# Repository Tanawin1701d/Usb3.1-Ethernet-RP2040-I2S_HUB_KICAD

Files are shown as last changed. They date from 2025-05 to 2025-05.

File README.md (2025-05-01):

# Usb3.1-Ethernet-RP2040-I2S_HUB_KICAD

- This project relies on Kicad 9.0

## features

### input
- usb 3.1 gen2
### output
- usb 3.0 (2 ports)
- ethernet (1 rj45 port)
- microphone + speaker (stero 3mm jack)
### processor & ic
- Rasberry pi (RP2040)
- tmp235 (temperature sensor)
- tusb8041 (usb hub)
- RTL8153B-VB (ethernet)

### repo structure

```
F---- doc (document for each ICs)
F---- finalProj
           |F---- hub (kicad file)
F---- symFoot (footprint for each ICs)
D---- bom.xlsx (bill of material for all components except pcb board)
```

## preview

### schematic

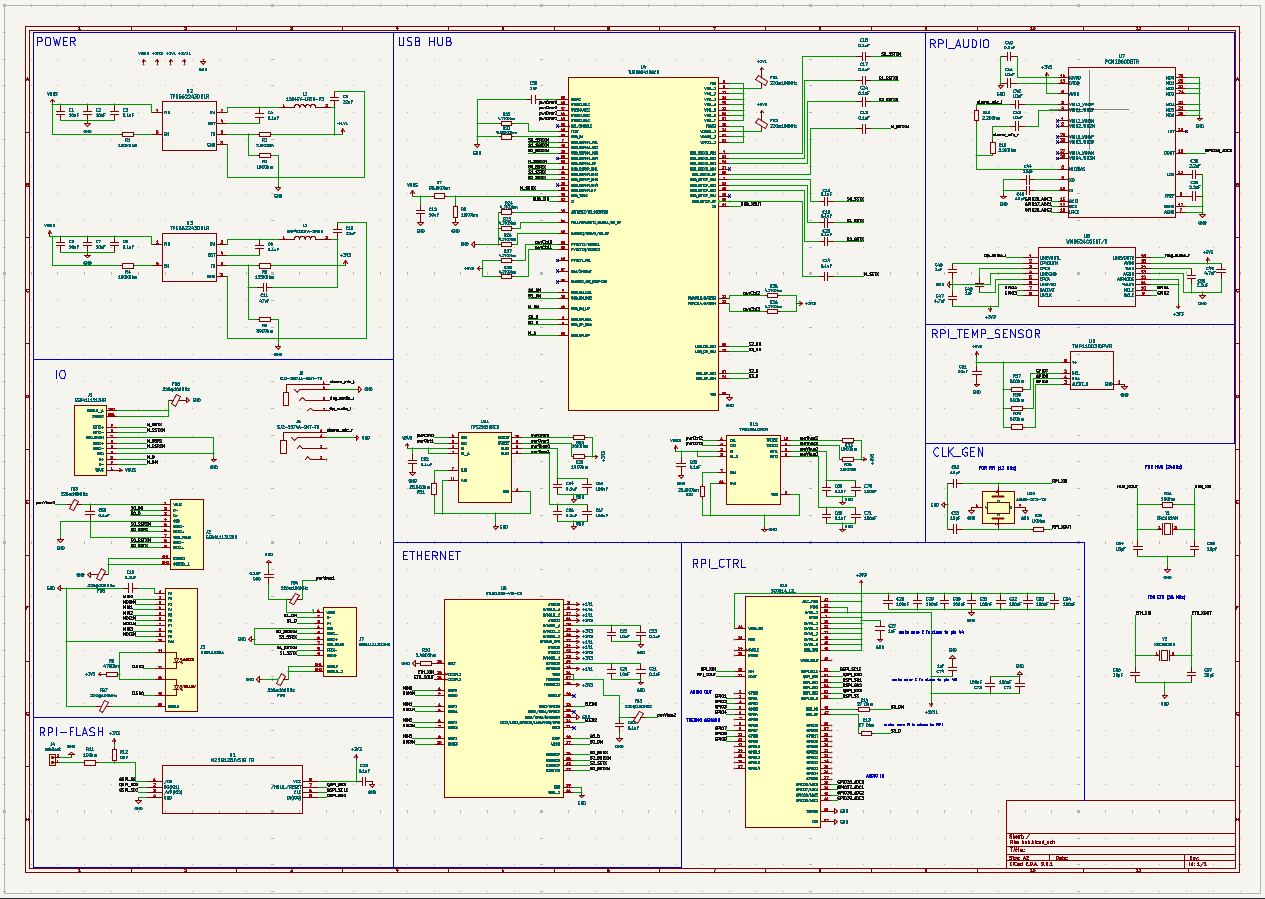
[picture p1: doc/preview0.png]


### layout

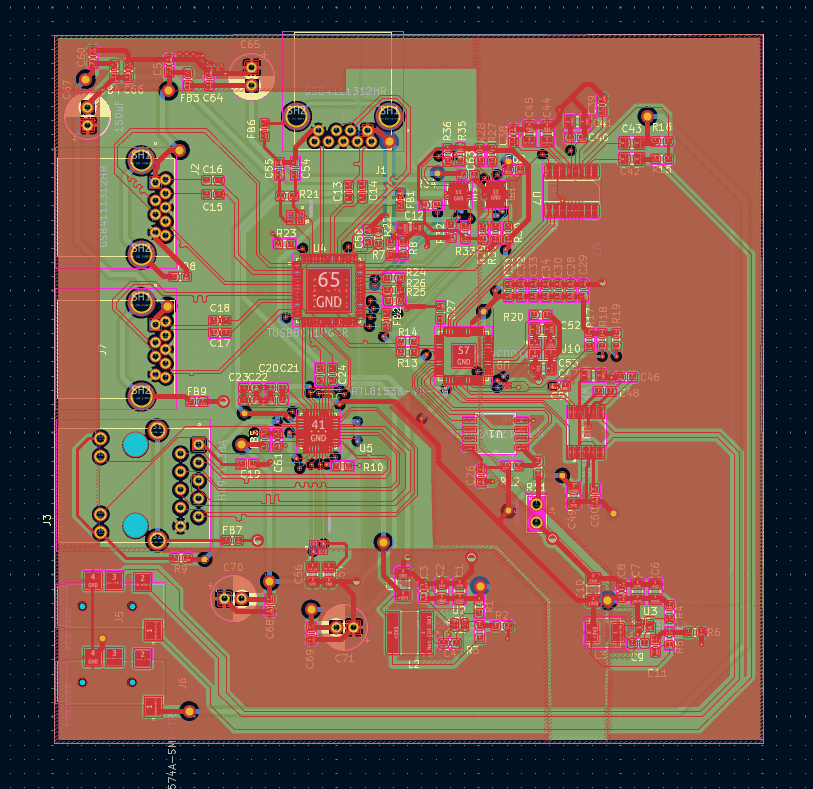
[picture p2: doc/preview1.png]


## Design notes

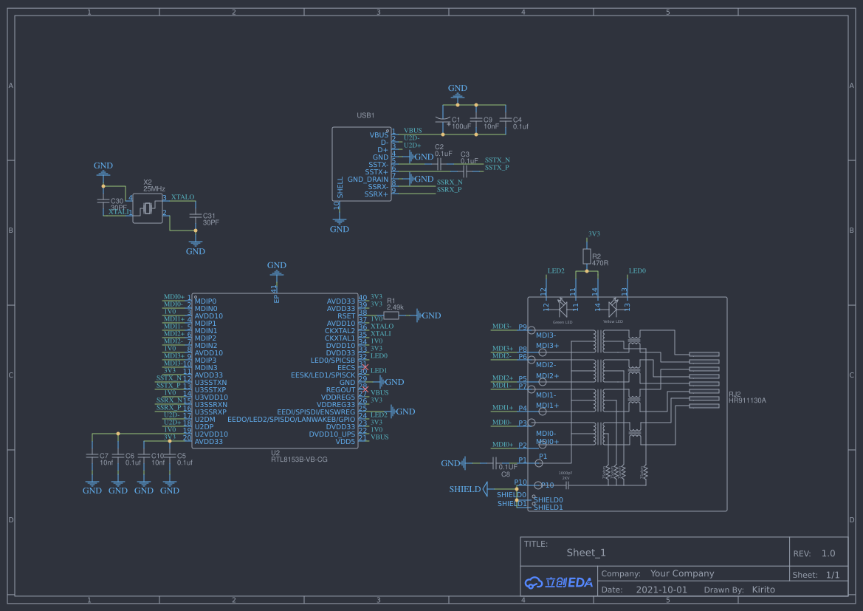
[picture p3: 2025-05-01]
symFoot/ethernetExample.png

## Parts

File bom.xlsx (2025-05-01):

Reference | Footprint | voltage rating | tol | temp coff | price |  |  |  | Value | Datasheet | DNP | Exclude from BOM | Exclude from Board | source
C1,C2,C6,C7,C12,C41,C42,C43 | Capacitor_SMD:C_0805_2012Metric_Pad1.18x1.45mm_HandSolder | 10 | +-10 | x7r | 0.38 |  | 8 | 3.04 | 10uF | ~ |  |  |  | https://www.digikey.co.th/en/products/detail/samsung-electro-mechanics/CL21B106KPQNNNE/3887422
C3,C4,C8,C9,C13,C14,C15,C16,C17,C18,C19,C21,C23,C24,C25,C26,C40,C59,C60,C61,C62,C63,C64,C66,C68,C69 | Capacitor_SMD:C_0603_1608Metric_Pad1.08x0.95mm_HandSolder | 25 | +-10 | x7r | 0.01500 |  | 26 | 0.39 | 0.1uF | ~ |  |  |  | https://www.digikey.co.th/en/products/detail/samsung-electro-mechanics/CL10B104KA8NNNC/3886664
C5,C10 | Capacitor_SMD:C_1206_3216Metric_Pad1.33x1.80mm_HandSolder | 10 | +-20 | x7r | 0.20300 |  | 2 | 0.406 | 22uF | ~ |  |  |  | https://www.digikey.co.th/en/products/detail/samsung-electro-mechanics/CL31B226MPHNNNE/3888806
C11 | Capacitor_SMD:C_0603_1608Metric_Pad1.08x0.95mm_HandSolder | 50 | +-10 | x7r | 0.10200 |  | 1 | 0.102 | 47pF | ~ |  |  |  | https://www.digikey.co.th/en/products/detail/kyocera-avx/06035C470KAT2A/3080637
C20,C22,C51 | Capacitor_SMD:C_0603_1608Metric_Pad1.08x0.95mm_HandSolder | 50 | +-10 | x7r | 0.00900 |  | 3 | 0.027 | 10nF | ~ |  |  |  | https://www.digikey.co.th/en/products/detail/samsung-electro-mechanics/CL10B103KB8NNNC/3886667
C27,C46,C48,C58,C74 | Capacitor_SMD:C_0603_1608Metric_Pad1.08x0.95mm_HandSolder | 10 | +-10 | x7r | 0.00600 |  | 5 | 0.03 | 1uF | ~ |  |  |  | https://www.digikey.co.th/en/products/detail/samsung-electro-mechanics/CL10B105KP8NNNC/3887604
C28,C29,C30,C31,C32,C33,C34,C72,C73 | Capacitor_SMD:C_0603_1608Metric_Pad1.08x0.95mm_HandSolder | 25 | +-10 | x7r | 0.01500 |  | 9 | 0.135 | 0.1uF | ~ |  |  |  | https://www.digikey.co.th/en/products/detail/samsung-electro-mechanics/CL10B104KA8NNNC/3886664
C38,C39,C50 | Capacitor_SMD:C_0603_1608Metric_Pad1.08x0.95mm_HandSolder | 10 | +-10 | x7r | 0.02100 |  | 3 | 0.063 | 2.2uF | ~ |  |  |  | https://www.digikey.co.th/en/products/detail/samsung-electro-mechanics/CL10B225KP8NNNC/3886792
C44,C45,C52,C53 | Capacitor_SMD:C_0805_2012Metric_Pad1.18x1.45mm_HandSolder | 50 | +-10 | x7r | 0.10600 |  | 4 | 0.424 | 15pF | ~ |  |  |  | https://www.digikey.co.th/en/products/detail/kyocera-avx/08055C150KAT2A/1602879
C47,C49 | Capacitor_SMD:C_0805_2012Metric_Pad1.18x1.45mm_HandSolder | 16 | +-10 | x7r | 0.10800 |  | 2 | 0.216 | 4.7uF | ~ |  |  |  | https://www.digikey.co.th/en/products/detail/samsung-electro-mechanics/CL21B475KOFNFNE/3888628
C54,C55 | Capacitor_SMD:C_0603_1608Metric_Pad1.08x0.95mm_HandSolder | 50 | +-10 | x7r | 0.12900 |  | 2 | 0.258 | 18pF | ~ |  |  |  | https://www.digikey.co.th/en/products/detail/kemet/C0603C180K5RACTU/12700994
C56,C57 | 0805 (2012 Metric) | 50 | +-10 | x7r | 0.17300 |  | 2 | 0.346 | 30pF | ~ |  |  |  | https://www.digikey.co.th/en/products/detail/kemet/C0805C300K5RACAUTO/18127792
C65,C67,C70,C71 | custom (polar ) | 6.3 | +-20 | x7r | 0.22400 |  | 4 | 0.896 | 150uF | ~ |  |  |  | https://www.digikey.co.th/en/products/detail/rubycon/25ZLJ150M6-3X11/3134203
FB1,FB2,FB3,FB4,FB5,FB6,FB7,FB8,FB9 | 603 |  |  |  | 0.057 |  | 9 | 0.513 | 220@100MHz | ~ |  |  |  | https://www.digikey.co.th/en/products/detail/tdk-corporation/MPZ1608S221ATA00/571872
J1 | GSB4111312HR:AMPHENOL_GSB4111312HR |  |  |  | 0.92 |  | 3 | 2.76 | GSB4111312HR |  |  |  |  | https://www.digikey.co.th/en/products/detail/amphenol-cs-commercial-products/GSB4111312HR/4883780
J3 | HR911130A:HANRUN_HR911130A |  |  |  | 1.14302 |  | 1 | 1.14302 | HR911130A |  |  |  |  | https://www.chipspulse.com/product/Hanrun/HR911130A.html?utm_source=digipart&sku=HR911130A
J4 | pin01x02:61300211121 |  |  |  | 0.113 |  | 1 | 0.113 | usbBoot |  |  |  |  | https://th.mouser.com/ProductDetail/Wurth-Elektronik/61300211121?qs=t4813l51qx%252B1A5GYDQxPlw%3D%3D
J5,J6 | SJ2_3574A_SMT_TR:SAMESKY_SJ2-3574A-SMT-TR |  |  |  | 0.87 |  | 2 | 1.74 | SJ2-3574A-SMT-TR |  |  |  |  | https://www.digikey.co.th/en/products/detail/same-sky-formerly-cui-devices/SJ2-3574A-SMT-TR/6619530
L1 | custom |  |  |  | 0.328 |  | 1 | 0.328 | 1.2uH | ~ |  |  |  | https://www.digikey.co.th/en/products/detail/murata-electronics/1264EY-1R2N-P3/6205581
L2 | custom |  |  |  | 0.838 |  | 1 | 0.838 | 3.3uH(SRP4020TA_3R3M) | ~ |  |  |  | https://www.digikey.co.th/en/products/detail/bourns-inc/SRP4020TA-3R3M/4901005
R1,R4 | Resistor_SMD:R_0603_1608Metric_Pad0.98x0.95mm_HandSolder |  |  |  | 0.027 |  | 2 | 0.054 | 100KOhm | ~ |  |  |  | https://www.digikey.co.th/en/products/detail/susumu/RR0816P-104-D/432233
R2,R8,R29,R30,R33,R34 | Resistor_SMD:R_0603_1608Metric_Pad0.98x0.95mm_HandSolder |  |  |  | 0.033 |  | 6 | 0.198 | 10KOhm | ~ |  |  |  | https://www.digikey.co.th/en/products/detail/panasonic-electronic-components/ERJ-3GEYJ103V/135662
R3 | Resistor_SMD:R_0603_1608Metric_Pad0.98x0.95mm_HandSolder |  |  |  | 0.009 |  | 1 | 0.009 | 7.5KOhm | ~ |  |  |  | https://www.digikey.co.th/en/products/detail/yageo/RC0603FR-077K5L/727366
R5 | Resistor_SMD:R_0603_1608Metric_Pad0.98x0.95mm_HandSolder |  |  |  | 0.101 |  | 1 | 0.101 | 135KOhm | ~ |  |  |  | https://www.digikey.co.th/en/products/detail/yageo/RT0603BRD07135KL/5927893
R6 | Resistor_SMD:R_0603_1608Metric_Pad0.98x0.95mm_HandSolder |  |  |  | 0.008 |  | 1 | 0.008 | 30KOhm | ~ |  |  |  | https://www.digikey.co.th/en/products/detail/yageo/RC0603JR-0730KL/726768
R7 | Resistor_SMD:R_0603_1608Metric_Pad0.98x0.95mm_HandSolder |  |  |  | 0.009 |  | 1 | 0.009 | 90.9KOhm | ~ |  |  |  | https://www.digikey.co.th/en/products/detail/yageo/RC0603FR-0790K9L/727424
R9 | Resistor_SMD:R_0603_1608Metric_Pad0.98x0.95mm_HandSolder |  |  |  | 0.008 |  | 1 | 0.008 | 470Ohm | ~ |  |  |  | https://www.digikey.co.th/en/products/detail/yageo/RC0603JR-07470RL/726791
R10 | Resistor_SMD:R_0603_1608Metric_Pad0.98x0.95mm_HandSolder |  |  |  | 0.03 |  | 1 | 0.03 | 2.49KOhm | ~ |  |  |  | https://www.digikey.co.th/en/products/detail/vishay-dale/CRCW06032K49FKEAC/7928466
R11,R20 | Resistor_SMD:R_0603_1608Metric_Pad0.98x0.95mm_HandSolder |  |  |  | 0.02 |  | 2 | 0.04 | 1KOhm | ~ |  |  |  | https://www.digikey.co.th/en/products/detail/stackpole-electronics-inc/RMCF0603FT1K00/1761077
R12 | Resistor_SMD:R_0603_1608Metric_Pad0.98x0.95mm_HandSolder |  |  |  |  |  |  | 0 | DNF | ~
R13,R14 | Resistor_SMD:R_0603_1608Metric_Pad0.98x0.95mm_HandSolder |  |  |  | 0.008 |  | 2 | 0.016 | 27 Ohm | ~ |  |  |  | https://www.digikey.co.th/en/products/detail/yageo/RC0603JR-0727RL/726751
R15,R16 | Resistor_SMD:R_0603_1608Metric_Pad0.98x0.95mm_HandSolder |  |  |  | 0.028 |  | 2 | 0.056 | 2.2KOhm | ~ |  |  |  | https://www.digikey.co.th/en/products/detail/te-connectivity-passive-product/CRGCQ0603F2K2/8576294
R17,R18,R19 | Resistor_SMD:R_0603_1608Metric_Pad0.98x0.95mm_HandSolder |  |  |  | 0.139 |  | 3 | 0.417 | 5KOhm | ~ |  |  |  | https://www.digikey.co.th/en/products/detail/yageo/RT0603BRE075KL/7708365
R21 | Resistor_SMD:R_0603_1608Metric_Pad0.98x0.95mm_HandSolder |  |  |  | 0.009 |  | 1 | 0.009 | 1MOhm | ~ |  |  |  | https://www.digikey.co.th/en/products/detail/yageo/RC0603FR-071ML/726844
R22,R24,R25,R26,R27,R28,R35,R36 | Resistor_SMD:R_0603_1608Metric_Pad0.98x0.95mm_HandSolder |  |  |  | 0.009 |  | 8 | 0.072 | 4.7KOhm | ~ |  |  |  | https://www.digikey.co.th/en/products/detail/yageo/RC0603FR-074K7L/727212
R23 | Resistor_SMD:R_0603_1608Metric_Pad0.98x0.95mm_HandSolder |  |  |  | 0.009 |  | 1 | 0.009 | 9.53KOhm | ~ |  |  |  | https://www.digikey.co.th/en/products/detail/yageo/RC0603FR-079K53L/727421
R31,R32 | Resistor_SMD:R_0603_1608Metric_Pad0.98x0.95mm_HandSolder |  |  |  | 0.02 |  | 2 | 0.04 | 25.5KOhm | ~ |  |  |  | https://www.digikey.co.th/en/products/detail/stackpole-electronics-inc/RMCF0603FT25K5/1713829
U1 | SOIC_208MIL_WIN |  |  |  | 1.36 |  | 1 | 1.36 | W25Q128JVSIQ TR | W25Q128JVSIQ TR |  |  |  | https://www.mouser.com/ProductDetail/Winbond/W25Q128JVSIQ-TR?qs=qSfuJ%252Bfl%2Fd7vTyLA9kNdGw%3D%3D
U2,U3 | DRL0006A-MFG |  |  |  | 0.151 |  | 2 | 0.302 | TPS562243DRLR | TPS562243DRLR |  |  |  | https://www.digikey.co.th/en/products/detail/texas-instruments/TPS562243DRLR/24708501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
U4 | TUSB8041RGCR:QFN50P900X900X100-65N |  |  |  | 2.6719 |  | 1 | 2.6719 | TUSB8041RGCR |  |  |  |  | https://th.mouser.com/ProductDetail/Texas-Instruments/TUSB8041RGCR?qs=7z%252BmIopC6%2FKwkzK7LNbP%2Fg%3D%3D
U5 | RTL8153B-VB-CG:QFN40P500X500X90-41N |  |  |  | 2.6908 |  | 1 | 2.6908 | RTL8153B-VB-CG |  |  |  |  | https://www.lcsc.com/product-detail/Ethernet-Transceivers_Realtek-Semicon-RTL8153B-VB-CG_C2802072.html
U13 | SC0914_13_:QFN40P700X700X90-57N |  |  |  | 0.7 |  | 1 | 0.7 | MCU_RaspberryPi_RP2040_RP2040 |  |  |  |  | https://www.digikey.co.th/en/products/detail/raspberry-pi/SC0914-13/14306010?s=N4IgTCBcDaIE4AcwAYAsyQF0C%2BQ
U7 | DBT0030A_N |  |  |  | 2.65 |  | 1 | 2.65 | PCM1860DBTR | PCM1860DBTR |  |  |  | https://www.mouser.com/ProductDetail/Texas-Instruments/PCM1860DBTR?qs=bjKSiFBd6qkC2mCf4k418w%3D%3D
U8 | TSSOP16_DM013.B_CIR |  |  |  | 1.75 |  | 1 | 1.75 | WM8524CGEDT/R | WM8524CGEDT/R |  |  |  | https://www.digikey.co.th/en/products/detail/cirrus-logic-inc/WM8524CGEDT-R/5036730
U9 | DPW0005A-MFG |  |  |  | 0.27 |  | 1 | 0.27 | TMP110D3IDPWR | TMP110D3IDPWR |  |  |  | https://www.digikey.co.th/en/products/detail/texas-instruments/TMP110D3IDPWR/24768909
U10 | ABM8-272-T3:ABM8-272-T3 |  |  |  | 0.47 |  | 1 | 0.47 | ABM8-272-T3 |  |  |  |  | https://www.digikey.co.th/en/products/detail/abracon-llc/ABM8-272-T3/22472366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
U11,U12 | TPS2561DRCR:VREG_V62_16624-01YE |  |  |  | 0.844 |  | 2 | 1.688 | TPS2561DRCR |  |  |  |  | https://www.digikey.co.th/en/products/detail/texas-instruments/TPS2561DRCR/2262003
Y1 | XRCGB24M000F2P00R0:OSC_XRCGB24M000F2P00R0 |  |  |  | 0.273 |  | 1 | 0.273 | XRCGB24M |  |  |  |  | https://www.digikey.co.th/en/products/detail/murata-electronics/XRCGB24M000F2P00R0/4951998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
Y2 | XRCGB25M000F3M00R0:OSC_XRCGB25M000F3M00R0 |  |  |  | 0.269 |  | 1 | 0.269 | XRCGB25M |  |  |  |  | https://www.digikey.co.th/en/products/detail/murata-electronics/XRCGB25M000F3M00R0/2368378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
 |  |  |  |  |  | total | 29.93872 | us dollar

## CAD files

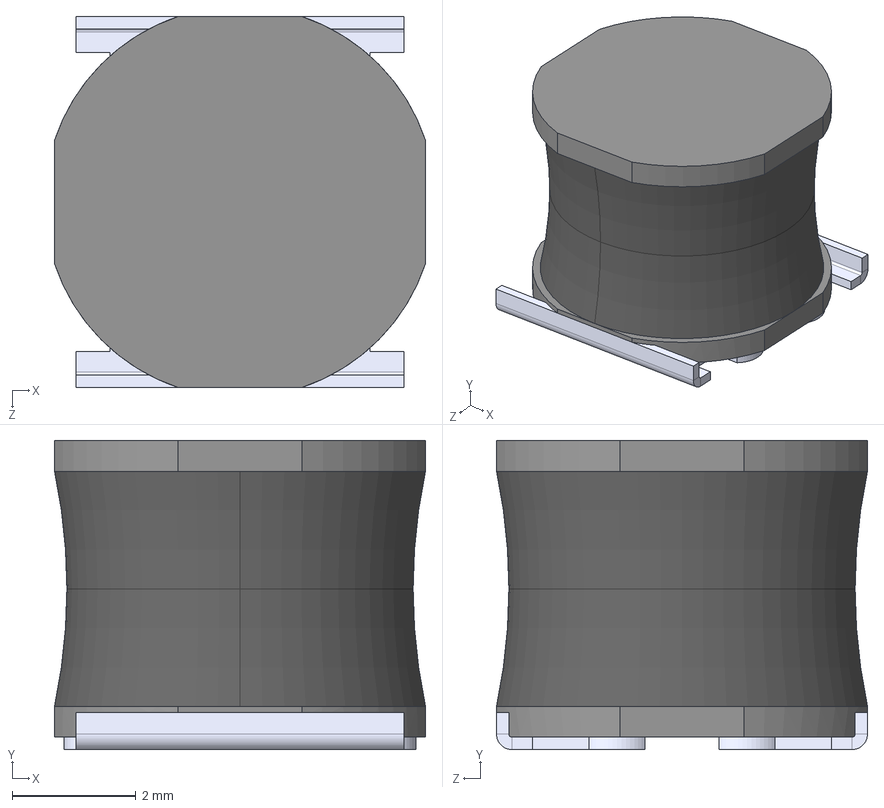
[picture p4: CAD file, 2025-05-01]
symFoot/1264EY_1R2N_P3/1264EY-1R2N_P3.step
6.00 x 5.00 x 6.00 mm

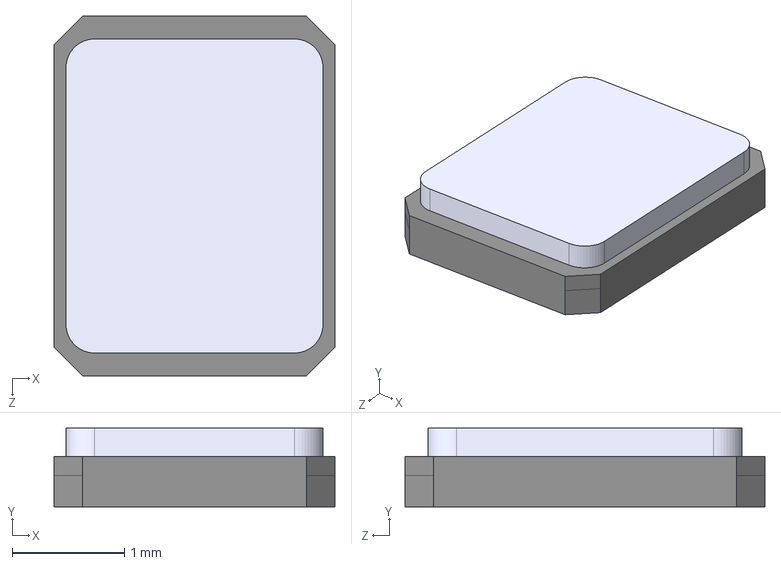
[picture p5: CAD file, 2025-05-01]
symFoot/ABM8-272-T3/ABM8-272-T3.step
2.50 x 0.7 x 3.20 mm

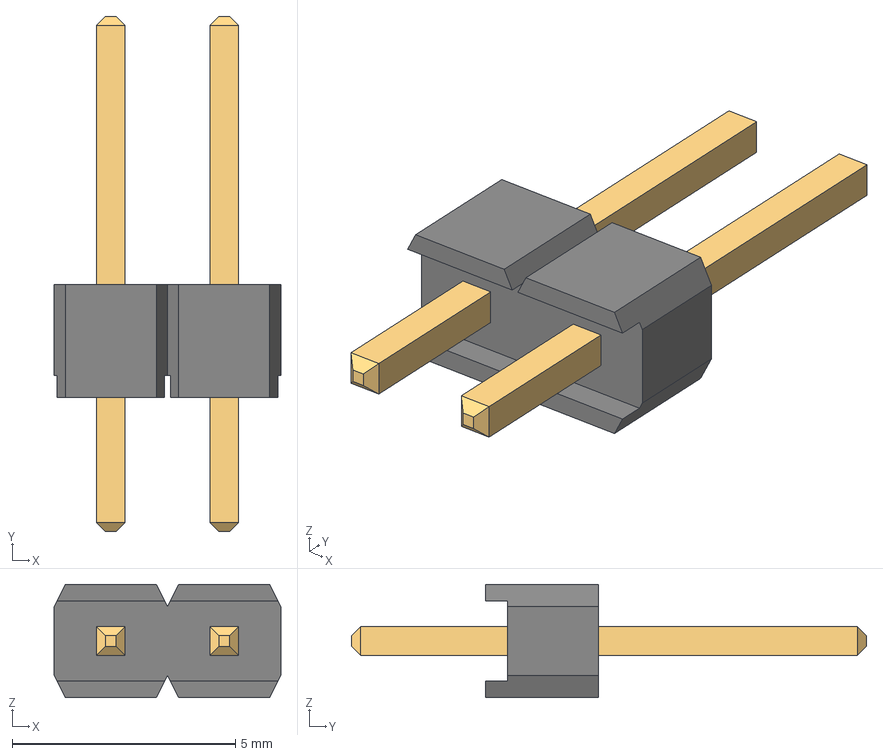
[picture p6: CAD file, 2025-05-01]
symFoot/pin01x02/6130XX11121_61300211121.step
5.08 x 11.5 x 2.54 mm
6130xx11121_PIN x 2

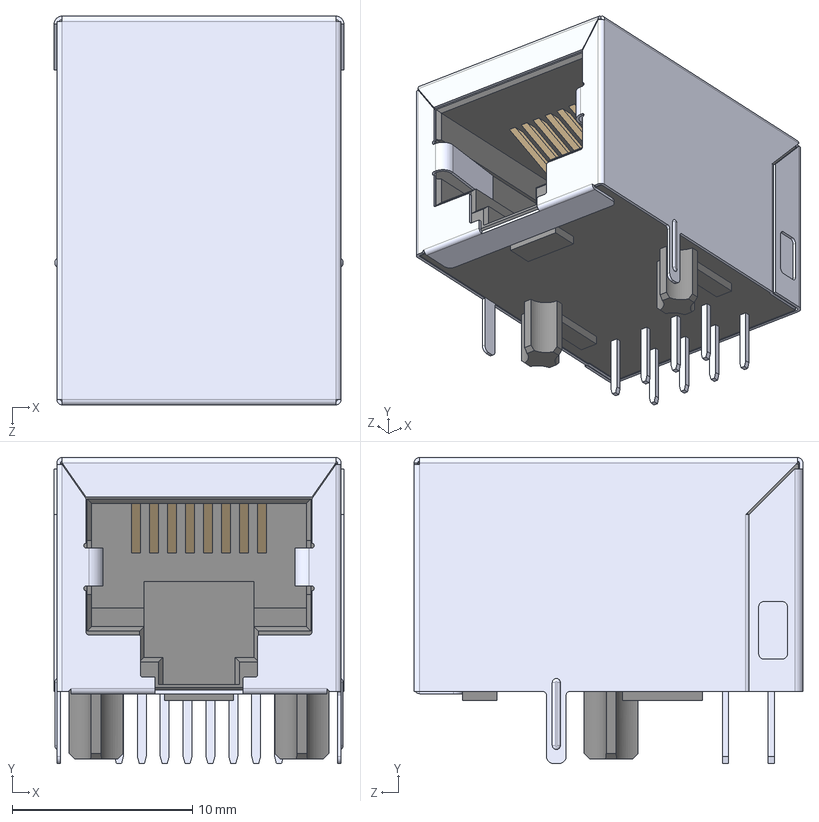
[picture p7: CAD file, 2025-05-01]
symFoot/rj45/RJMG1S8008101BR.step
16.1 x 17.0 x 21.6 mm

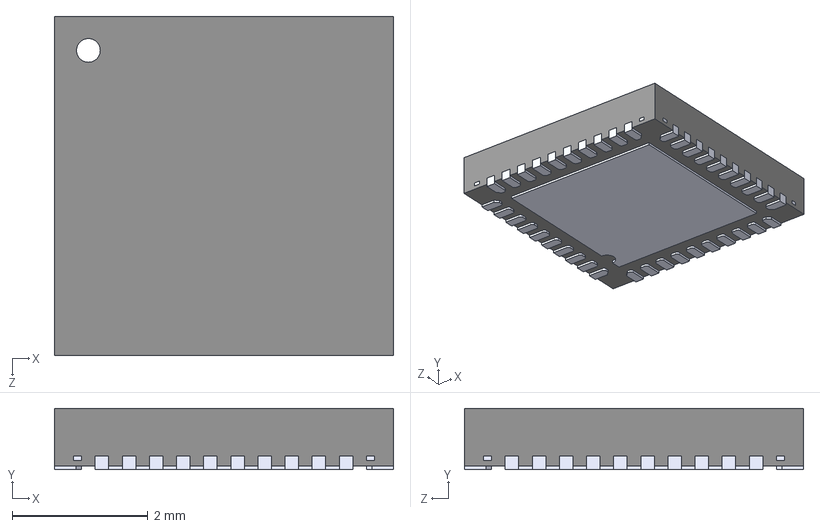
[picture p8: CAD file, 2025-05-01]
symFoot/RTL8153B-VB-CG/RTL8153B-VB-CG.step
5.00 x 0.9 x 5.00 mm

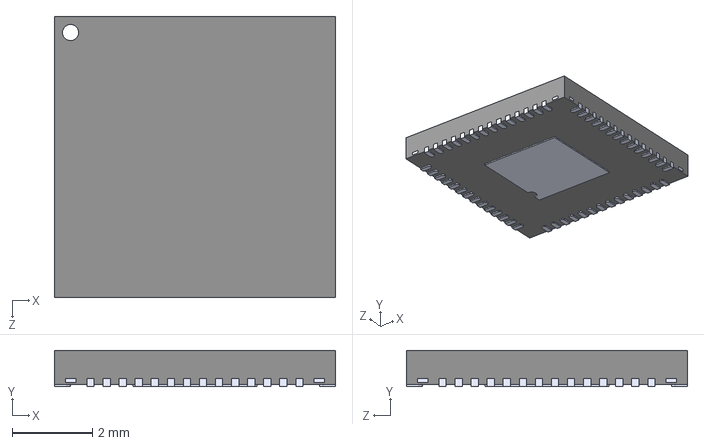
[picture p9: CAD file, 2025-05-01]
symFoot/SC0914_13_/SC0914_13_.step
7.00 x 0.9 x 7.00 mm

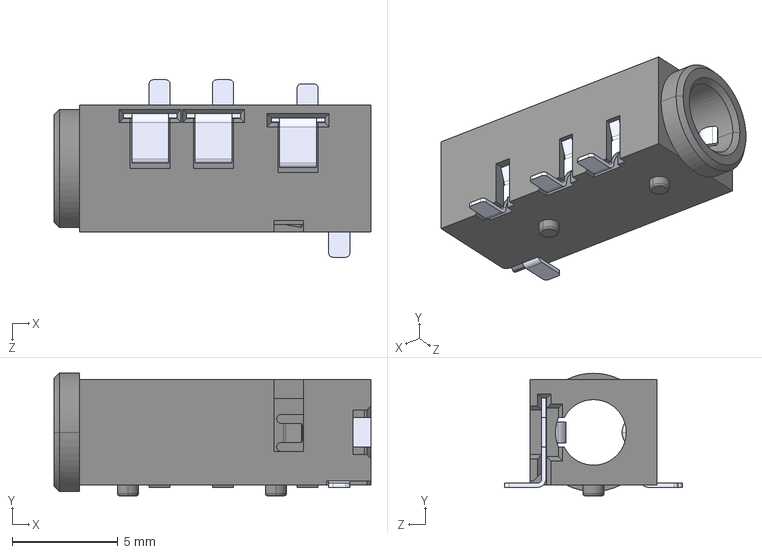
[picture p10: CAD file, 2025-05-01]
symFoot/SJ2_3574A_SMT_TR/SJ2-3574A-SMT-TR.step
15.0 x 5.80 x 8.40 mm

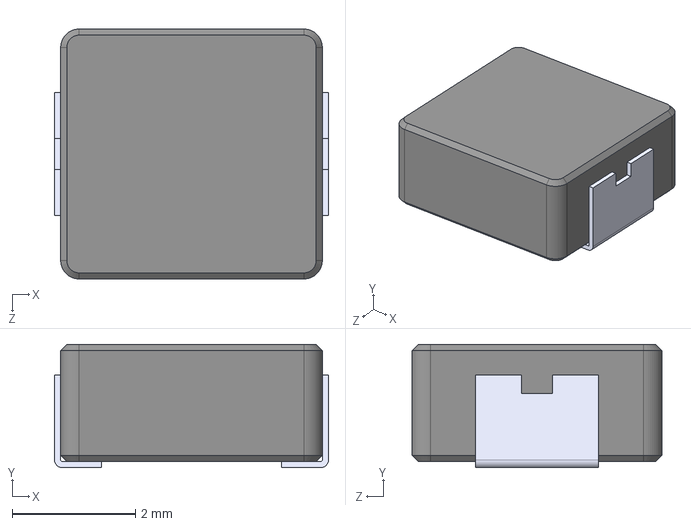
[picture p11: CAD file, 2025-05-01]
symFoot/SRP4020TA_3R3M/SRP4020TA-3R3M.step
4.45 x 2.00 x 4.06 mm

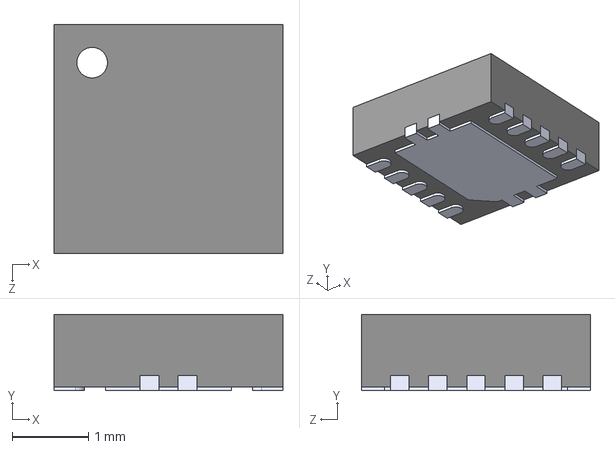
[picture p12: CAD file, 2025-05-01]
symFoot/TPS2561DRCR/TPS2561DRCR.step
3.00 x 1.00 x 3.00 mm

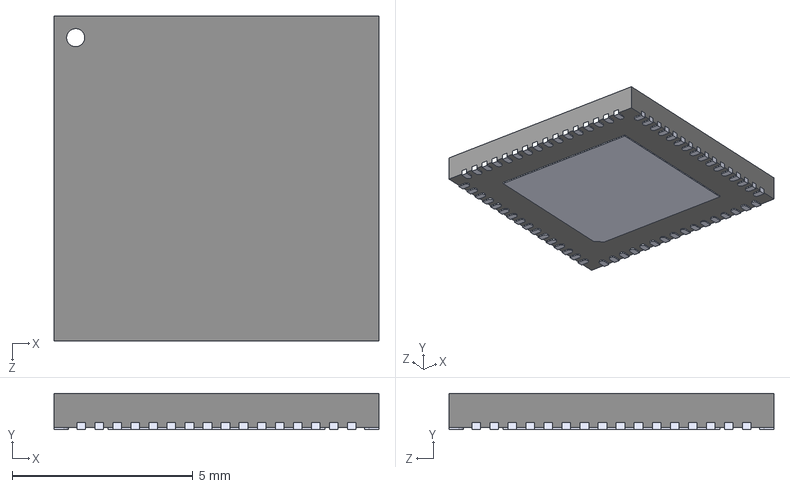
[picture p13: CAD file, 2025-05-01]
symFoot/TUSB8041RGCR/TUSB8041RGCR.step
9.00 x 1.00 x 9.00 mm

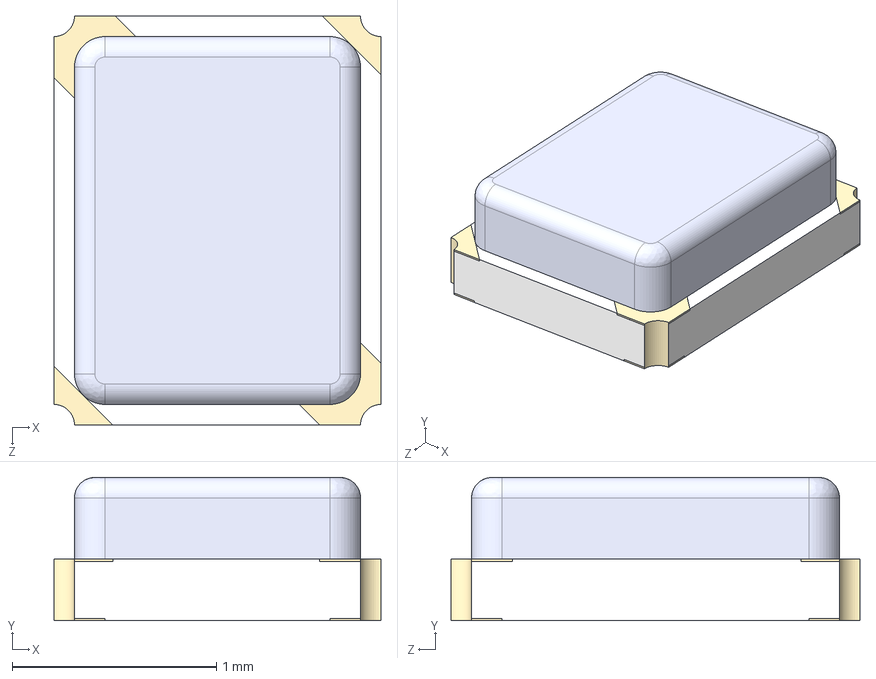
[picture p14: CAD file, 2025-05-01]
symFoot/XRCGB24M000F2P00R0/XRCGB24M000F2P00R0.step
1.60 x 0.7 x 2.00 mm

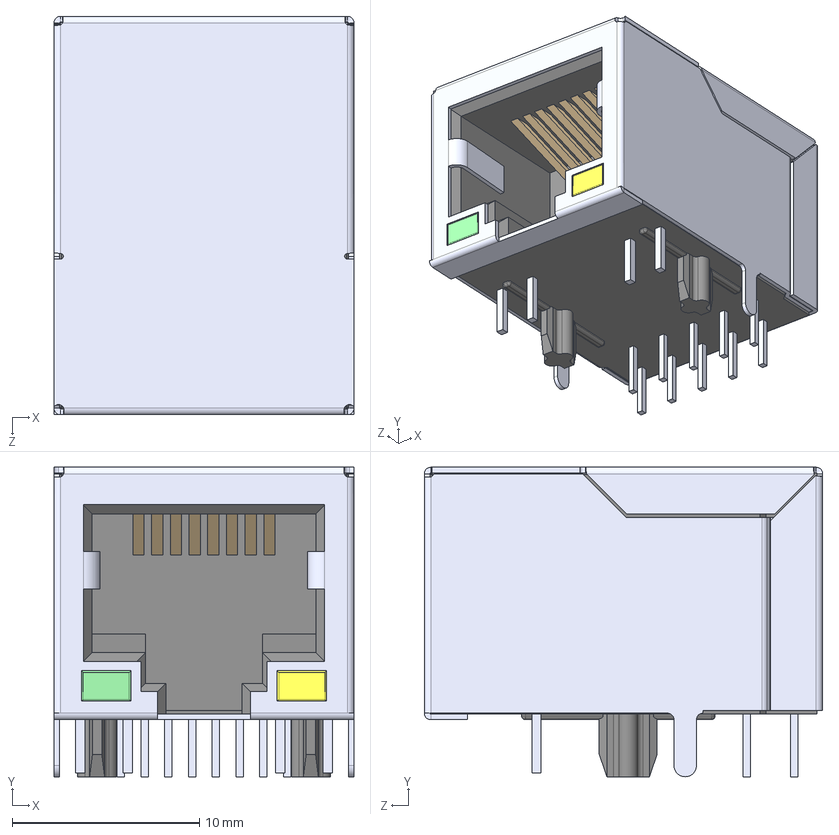
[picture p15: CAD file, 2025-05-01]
symFoot/HR911130A/HR911130A.step
16.0 x 16.6 x 21.3 mm

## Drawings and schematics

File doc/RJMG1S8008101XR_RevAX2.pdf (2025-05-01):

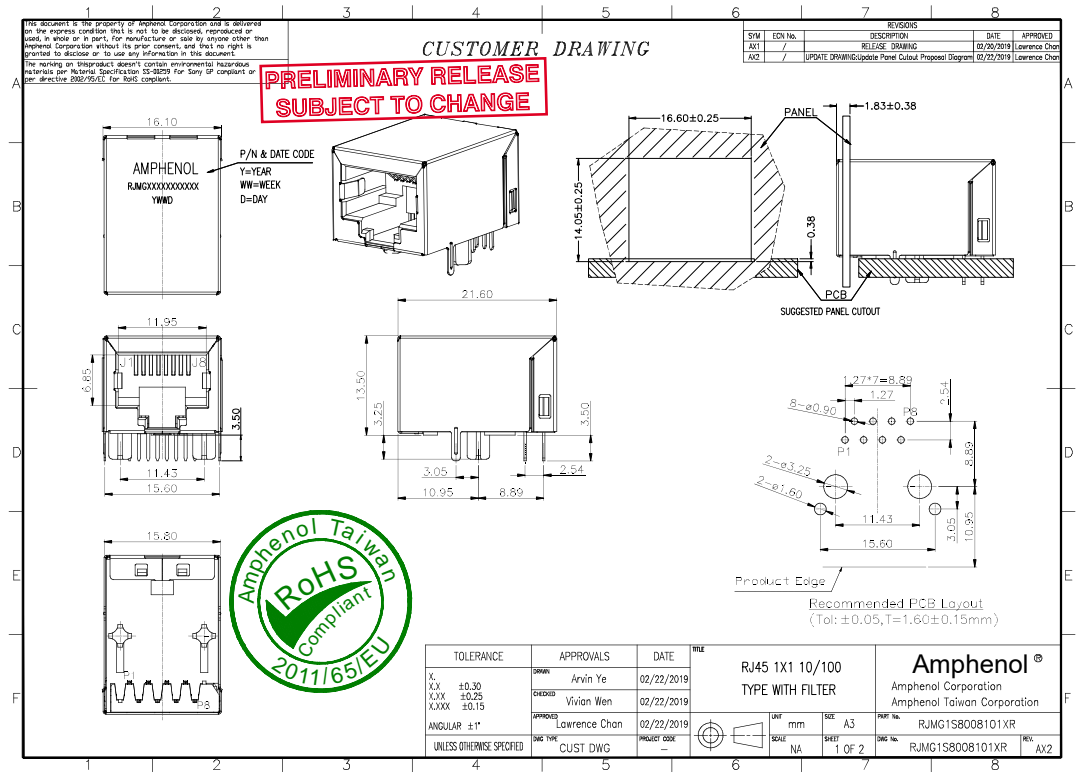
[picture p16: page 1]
Amphenol

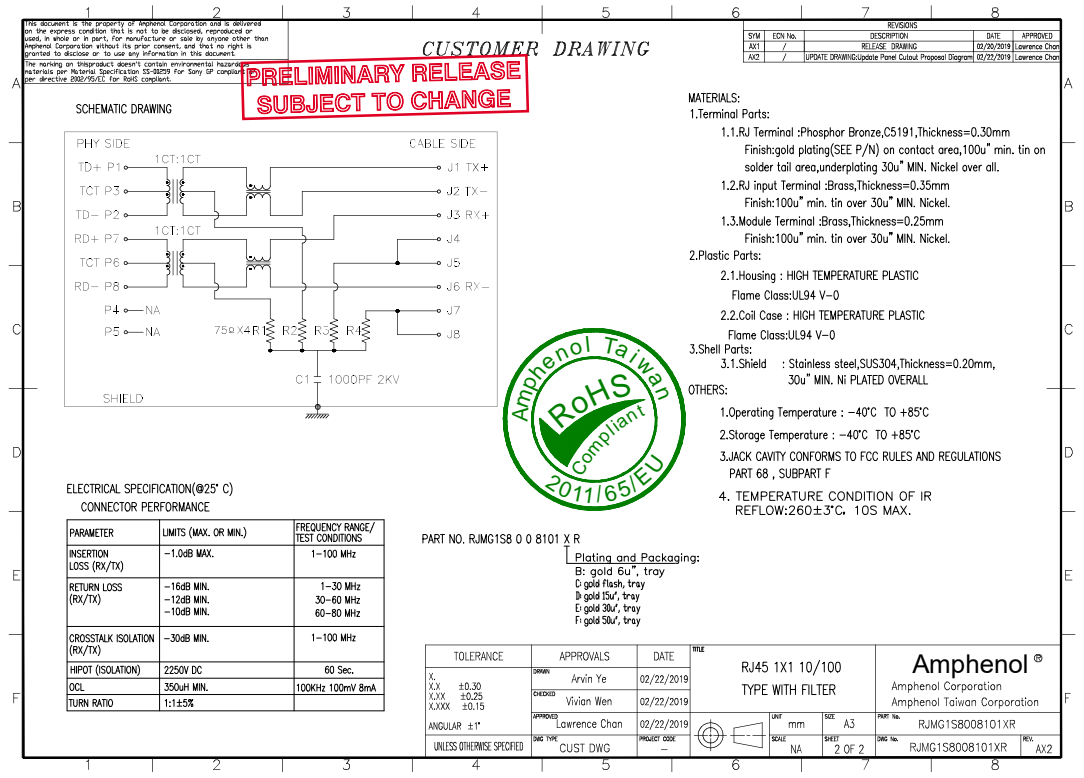
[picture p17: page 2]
Amphenol

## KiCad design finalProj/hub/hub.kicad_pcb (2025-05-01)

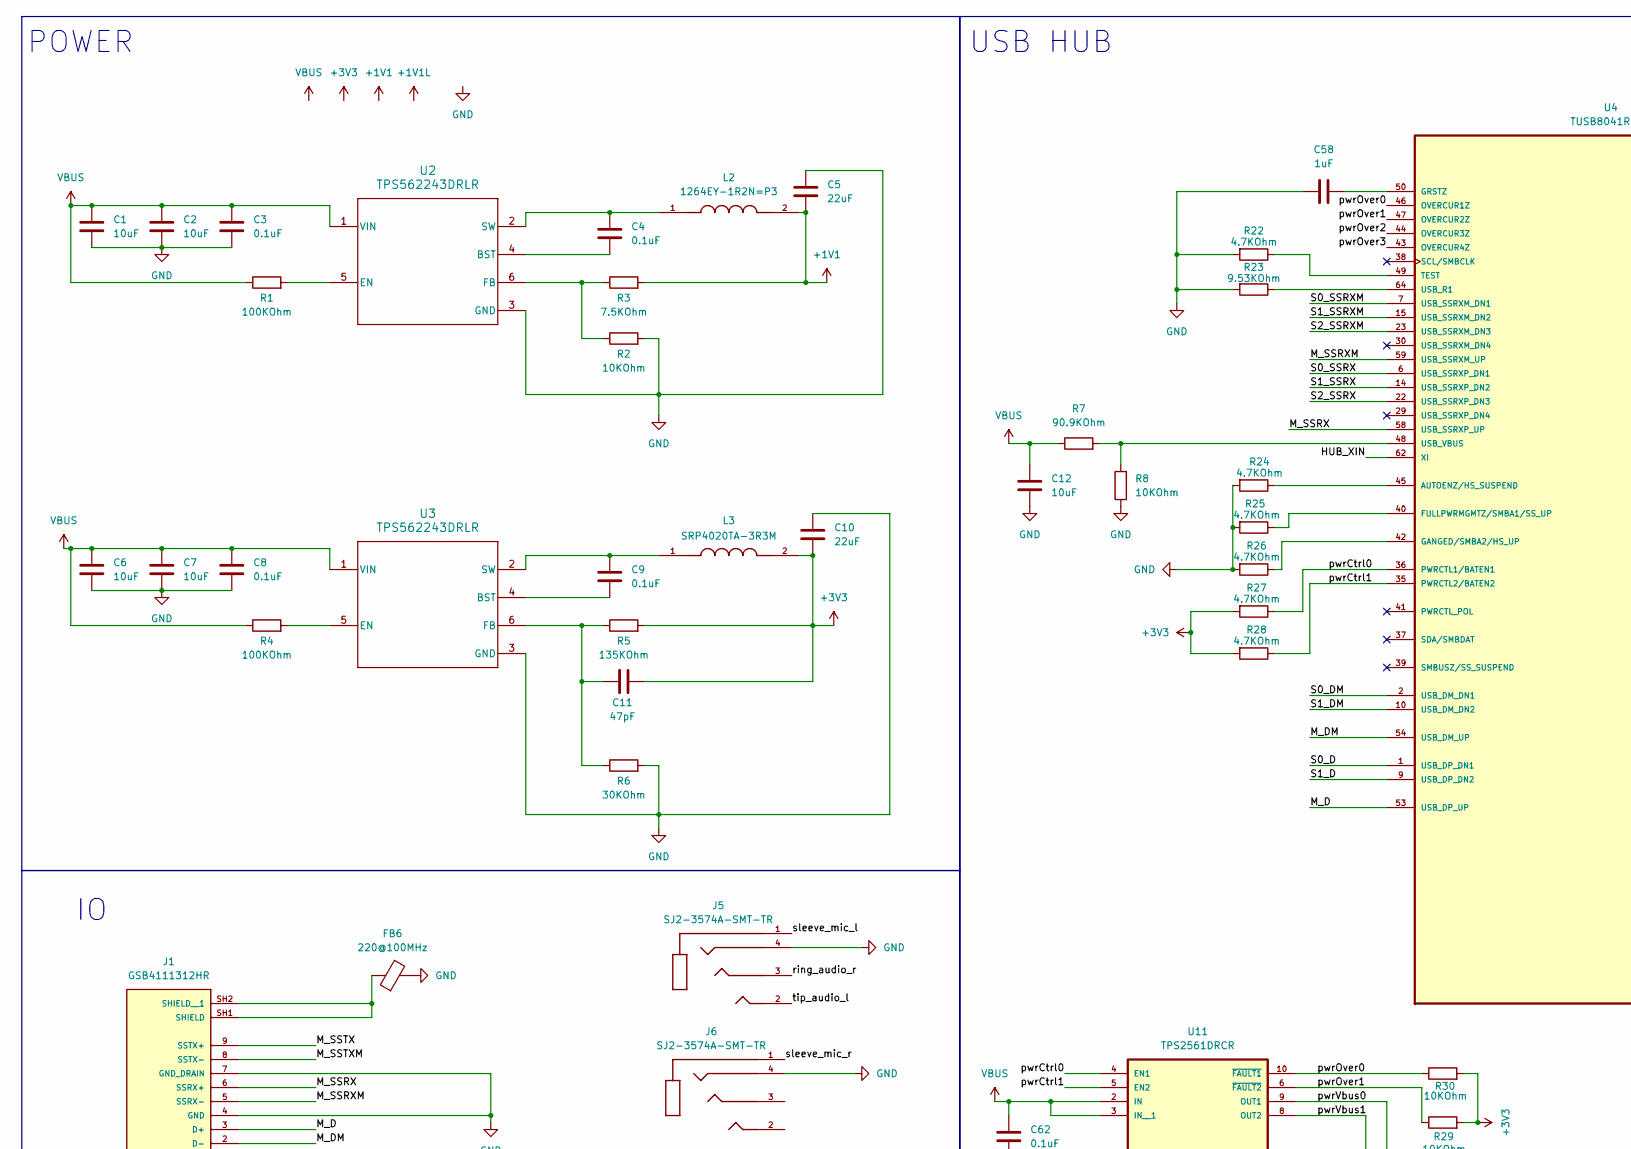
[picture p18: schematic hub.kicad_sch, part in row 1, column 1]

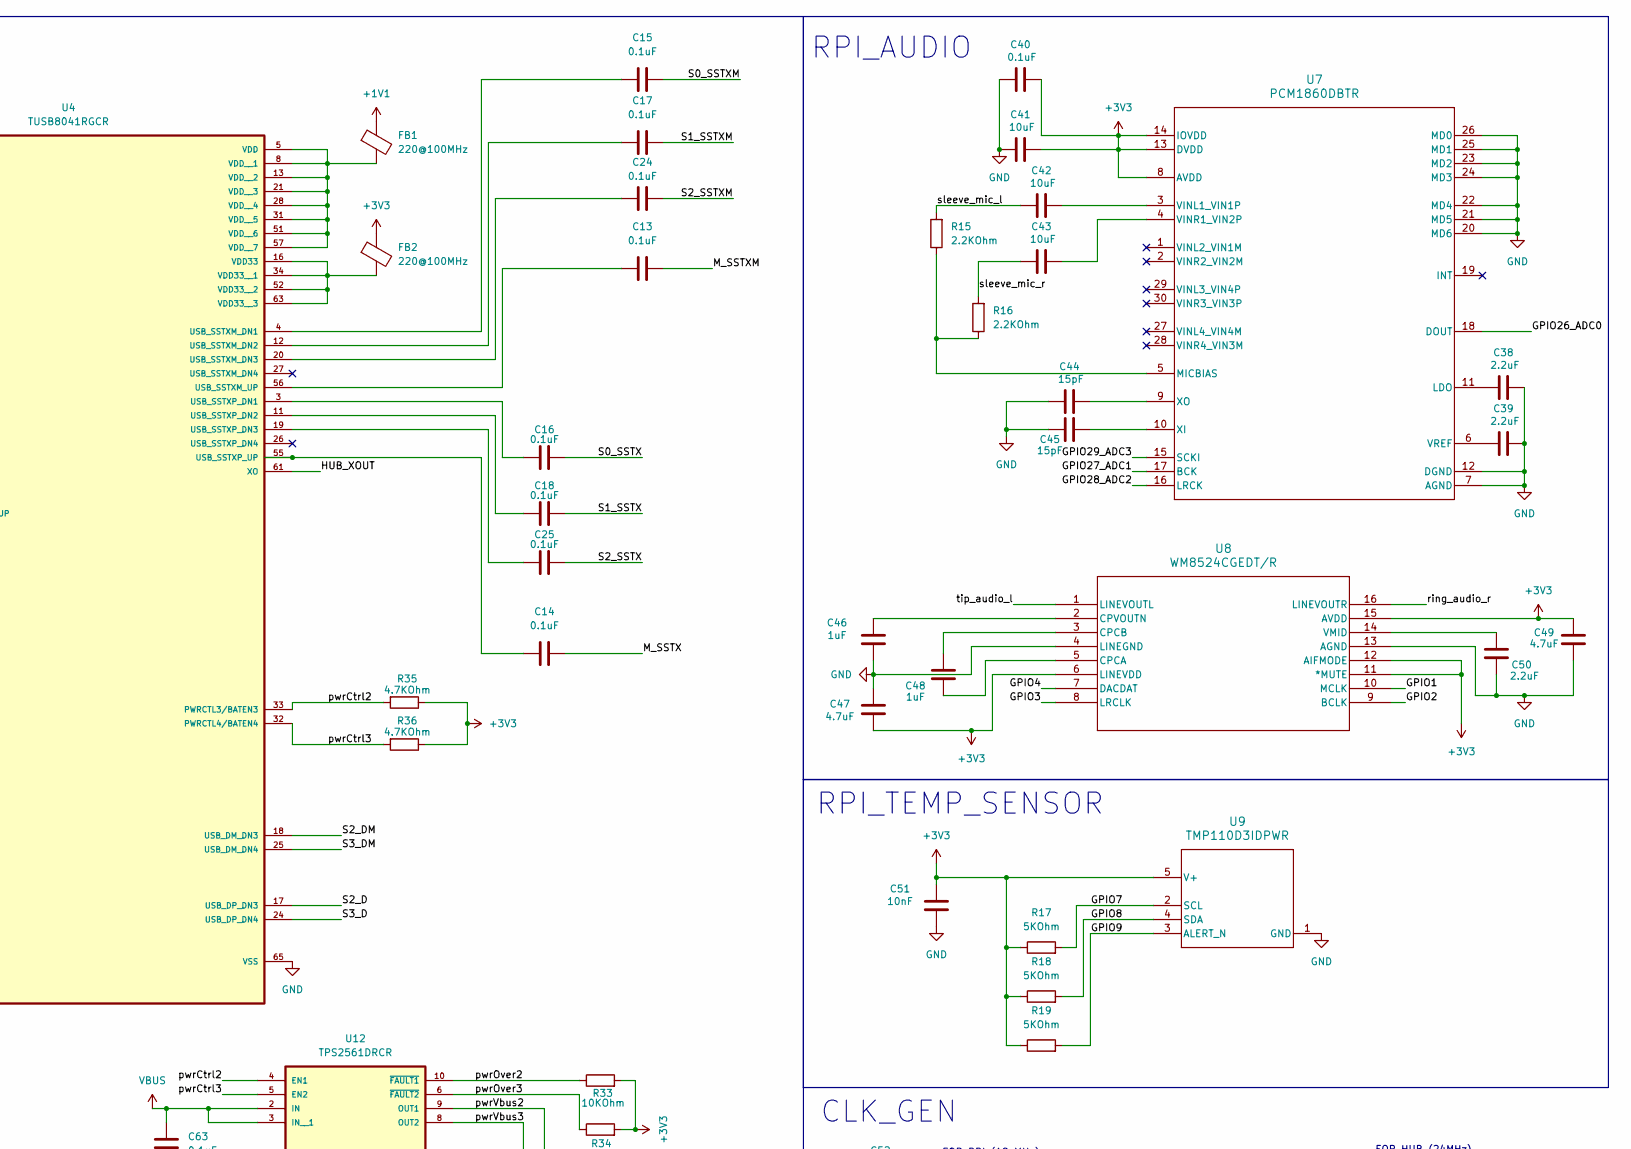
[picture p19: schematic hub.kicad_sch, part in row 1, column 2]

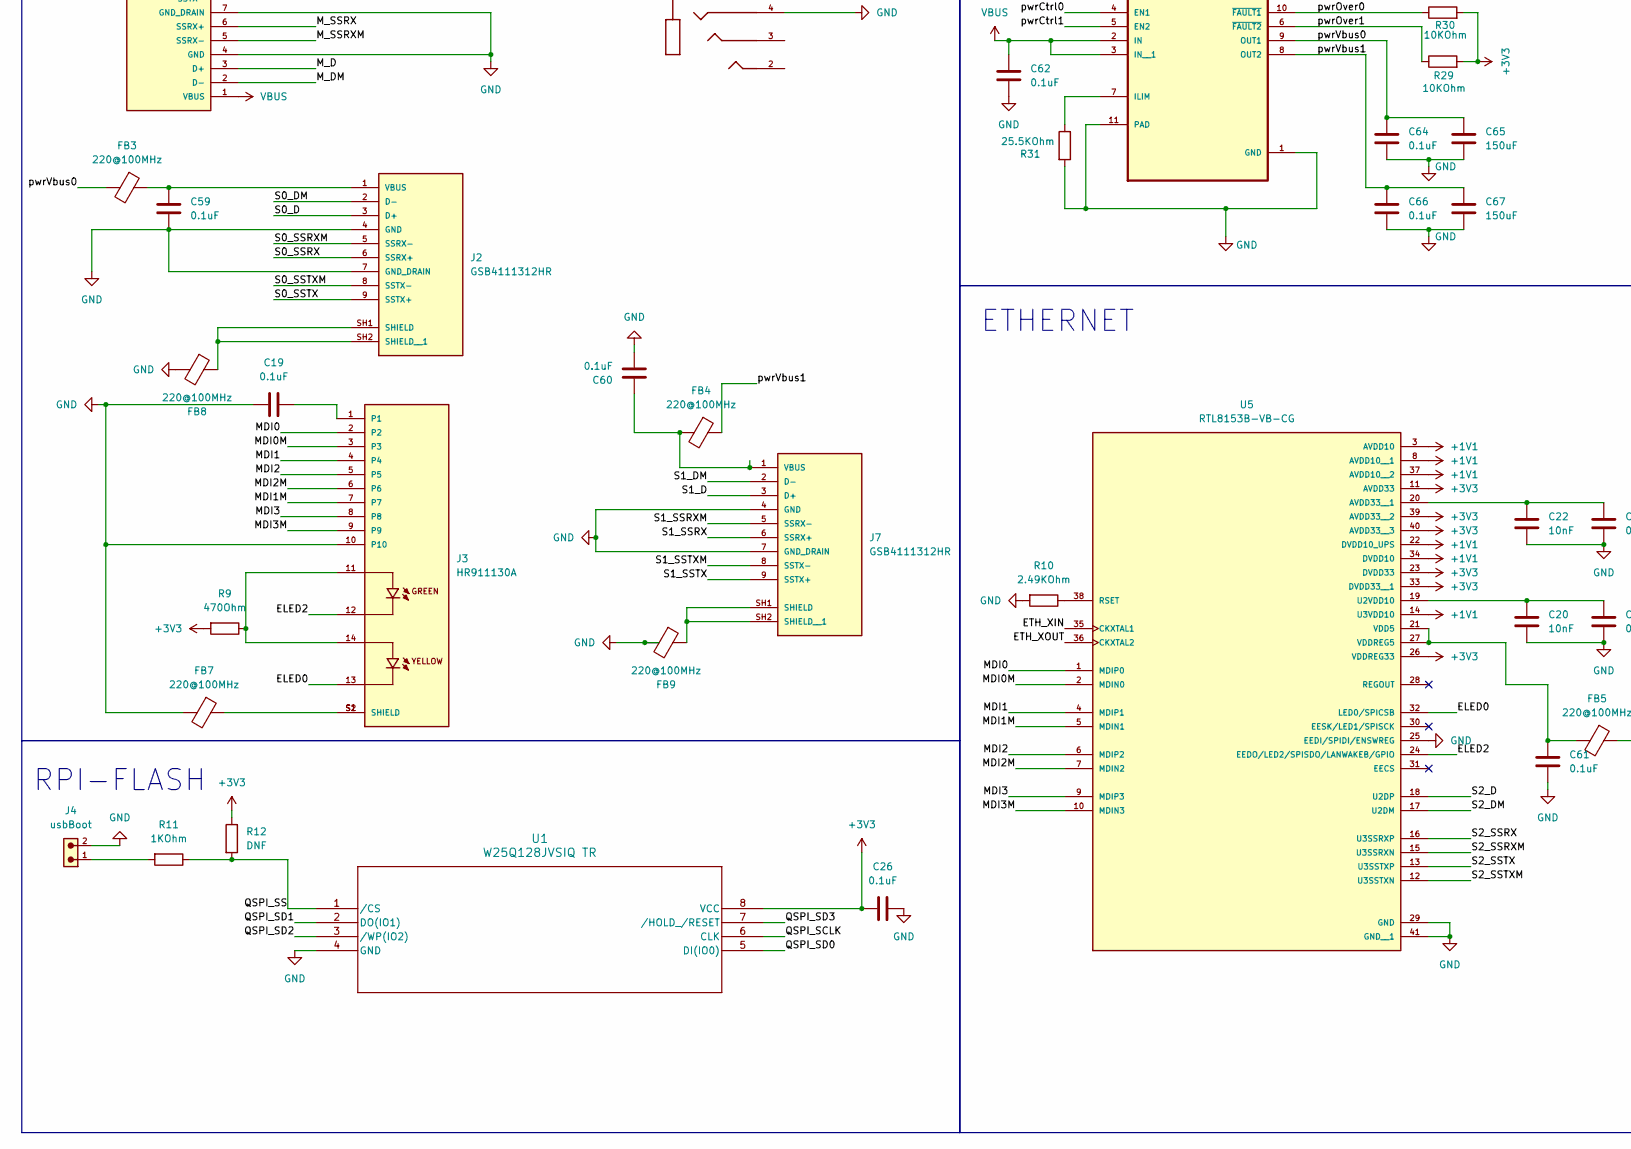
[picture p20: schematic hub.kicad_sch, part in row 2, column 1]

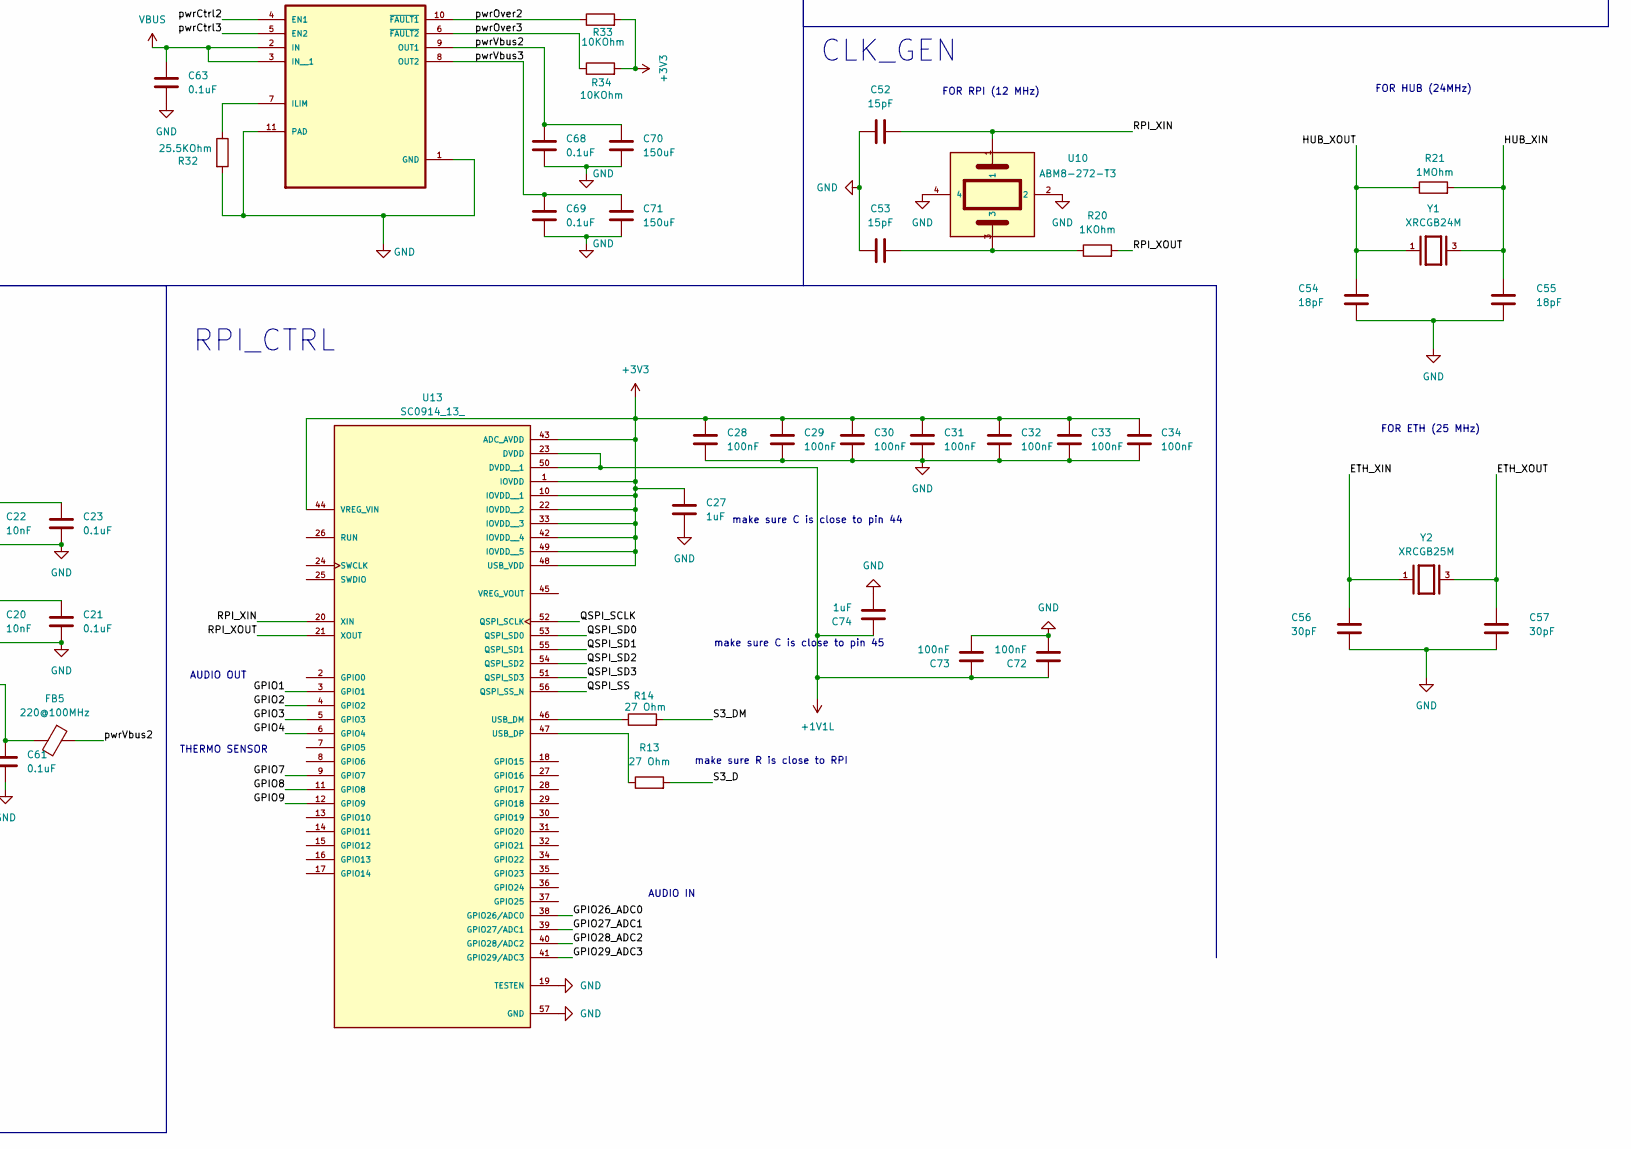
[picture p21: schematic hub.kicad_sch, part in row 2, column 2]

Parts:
C1, C2, C6, C7, C12, C41, C42, C43: 10uF; C_0805_2012Metric_Pad1.18x1.45mm_HandSolder
C3, C4, C8, C9, C13, C14, C15, C16, C17, C18, C19, C21, C23, C24, C25, C26, C40, C59, C60, C61, C62, C63, C64, C66, C68, C69: 0.1uF; C_0603_1608Metric_Pad1.08x0.95mm_HandSolder
C5, C10: 22uF; C_1206_3216Metric_Pad1.33x1.80mm_HandSolder
C11: 47pF; C_0603_1608Metric_Pad1.08x0.95mm_HandSolder
C20, C22, C51: 10nF; C_0603_1608Metric_Pad1.08x0.95mm_HandSolder
C27, C46, C48, C58, C74: 1uF; C_0603_1608Metric_Pad1.08x0.95mm_HandSolder
C28, C29, C30, C31, C32, C33, C34, C72, C73: 100nF; C_0603_1608Metric_Pad1.08x0.95mm_HandSolder
C38, C39, C50: 2.2uF; C_0603_1608Metric_Pad1.08x0.95mm_HandSolder
C44, C45, C52, C53: 15pF; C_0805_2012Metric_Pad1.18x1.45mm_HandSolder
C47, C49: 4.7uF; C_0805_2012Metric_Pad1.18x1.45mm_HandSolder
C54, C55: 18pF; C_0603_1608Metric_Pad1.08x0.95mm_HandSolder
C56, C57: 30pF; C_0805_2012Metric_Pad1.18x1.45mm_HandSolder
C65, C67, C70, C71: 150uF; CP_Radial_D6.3mm_P2.50mm
FB1, FB2, FB3, FB4, FB5, FB6, FB7, FB8, FB9: 220@100MHz; L_0603_1608Metric_Pad1.05x0.95mm_HandSolder
J1, J2, J7: GSB4111312HR; AMPHENOL_GSB4111312HR; PARTREV B
J3: HR911130A; HANRUN_HR911130A; PARTREV A
J4: usbBoot; 61300211121
J5, J6: SJ2-3574A-SMT-TR; SAMESKY_SJ2-3574A-SMT-TR; PARTREV 1.05
L2: 1264EY-1R2N=P3; IND_1264EY-1R2N=P3; PARTREV N/A
L3: SRP4020TA-3R3M; IND_SRP4020TA-3R3M
R1, R4: 100KOhm; R_0603_1608Metric_Pad0.98x0.95mm_HandSolder
R2, R8, R29, R30, R33, R34: 10KOhm; R_0603_1608Metric_Pad0.98x0.95mm_HandSolder
R3: 7.5KOhm; R_0603_1608Metric_Pad0.98x0.95mm_HandSolder
R5: 135KOhm; R_0603_1608Metric_Pad0.98x0.95mm_HandSolder
R6: 30KOhm; R_0603_1608Metric_Pad0.98x0.95mm_HandSolder
R7: 90.9KOhm; R_0603_1608Metric_Pad0.98x0.95mm_HandSolder
R9: 470Ohm; R_0603_1608Metric_Pad0.98x0.95mm_HandSolder
R10: 2.49KOhm; R_0603_1608Metric_Pad0.98x0.95mm_HandSolder
R11, R20: 1KOhm; R_0603_1608Metric_Pad0.98x0.95mm_HandSolder
R12: DNF; R_0603_1608Metric_Pad0.98x0.95mm_HandSolder
R13, R14: 27 Ohm; R_0603_1608Metric_Pad0.98x0.95mm_HandSolder
R15, R16: 2.2KOhm; R_0603_1608Metric_Pad0.98x0.95mm_HandSolder
R17, R18, R19: 5KOhm; R_0603_1608Metric_Pad0.98x0.95mm_HandSolder
R21: 1MOhm; R_0603_1608Metric_Pad0.98x0.95mm_HandSolder
R22, R24, R25, R26, R27, R28, R35, R36: 4.7KOhm; R_0603_1608Metric_Pad0.98x0.95mm_HandSolder
R23: 9.53KOhm; R_0603_1608Metric_Pad0.98x0.95mm_HandSolder
R31, R32: 25.5KOhm; R_0603_1608Metric_Pad0.98x0.95mm_HandSolder
U1: W25Q128JVSIQ TR; SOIC_208MIL_WIN
U2, U3: TPS562243DRLR; DRL0006A-MFG
U4: TUSB8041RGCR; QFN50P900X900X100-65N
U5: RTL8153B-VB-CG; QFN40P500X500X90-41N; PARTREV 1.4
U7: PCM1860DBTR; DBT0030A_N
U8: WM8524CGEDT/R; TSSOP16_DM013.B_CIR
U9: TMP110D3IDPWR; DPW0005A-MFG
U10: ABM8-272-T3
U11, U12: TPS2561DRCR; VREG_V62_16624-01YE
U13: SC0914_13_; QFN40P700X700X90-57N; PARTREV 2.2
Y1: XRCGB24M; OSC_XRCGB24M000F2P00R0; PARTREV N/A
Y2: XRCGB25M; OSC_XRCGB25M000F3M00R0; PARTREV N/A

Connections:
+1V1: C5.1, FB1.1, L2.2, R3.2, U5.3 (AVDD10), U5.8 (AVDD10__1), U5.14 (U3VDD10), U5.22 (DVDD10_UPS), U5.34 (DVDD10), U5.37 (AVDD10__2)
+3V3: C10.1, C11.1, C26.1, C27.1, C28.1, C29.1, C30.1, C31.1, C32.1, C33.1, C34.1, C40.2, C41.2, C47.1, C49.2, C51.2, FB2.1, L3.2, R5.2, R9.2, R12.1, R17.1, R18.1, R19.1, R27.2, R28.2, R29.2, R30.2, R33.2, R34.2, R35.1, R36.1, U1.8 (VCC), U5.11 (AVDD33), U5.23 (DVDD33), U5.26 (VDDREG33), U5.33 (DVDD33__1), U5.39 (AVDD33__2), U5.40 (AVDD33__3), U7.8 (AVDD), U7.13 (DVDD), U7.14 (IOVDD), U8.6 (LINEVDD), U8.11 (*MUTE), U8.12 (AIFMODE), U8.15 (AVDD), U9.5 (V+), U13.1 (IOVDD), U13.10 (IOVDD__1), U13.22 (IOVDD__2), U13.33 (IOVDD__3), U13.42 (IOVDD__4), U13.43 (ADC_AVDD), U13.44 (VREG_VIN), U13.48 (USB_VDD), U13.49 (IOVDD__5)
/ELED0: J3.13, U5.32 (LED0/SPICSB)
/ELED2: J3.12, U5.24 (EEDO/LED2/SPISDO/LANWAKEB/GPIO)
/ETH_XIN: C56.1, U5.35 (CKXTAL1), Y2.1
/ETH_XOUT: C57.1, U5.36 (CKXTAL2), Y2.3
/GPIO1: U8.10 (MCLK), U13.3 (GPIO1)
/GPIO2: U8.9 (BCLK), U13.4 (GPIO2)
/GPIO3: U8.8 (LRCLK), U13.5 (GPIO3)
/GPIO4: U8.7 (DACDAT), U13.6 (GPIO4)
/GPIO7: R17.2, U9.2 (SCL), U13.9 (GPIO7)
/GPIO8: R18.2, U9.4 (SDA), U13.11 (GPIO8)
/GPIO9: R19.2, U9.3 (ALERT_N), U13.12 (GPIO9)
/GPIO26_ADC0: U7.18 (DOUT), U13.38 (GPIO26/ADC0)
/GPIO27_ADC1: U7.17 (BCK), U13.39 (GPIO27/ADC1)
/GPIO28_ADC2: U7.16 (LRCK), U13.40 (GPIO28/ADC2)
/GPIO29_ADC3: U7.15 (SCKI), U13.41 (GPIO29/ADC3)
/HUB_XIN: C55.1, R21.2, U4.62 (XI), Y1.3
/HUB_XOUT: C54.1, R21.1, U4.61 (XO), Y1.1
/MDI0: J3.2, U5.1 (MDIP0)
/MDI0M: J3.3, U5.2 (MDIN0)
/MDI1: J3.4, U5.4 (MDIP1)
/MDI1M: J3.7, U5.5 (MDIN1)
/MDI2: J3.5, U5.6 (MDIP2)
/MDI2M: J3.6, U5.7 (MDIN2)
/MDI3: J3.8, U5.9 (MDIP3)
/MDI3M: J3.9, U5.10 (MDIN3)
/M_D: J1.3 (D+), U4.53 (USB_DP_UP)
/M_DM: J1.2 (D-), U4.54 (USB_DM_UP)
/M_SSRX: J1.6 (SSRX+), U4.58 (USB_SSRXP_UP)
/M_SSRXM: J1.5 (SSRX-), U4.59 (USB_SSRXM_UP)
/M_SSTX: C14.2, J1.9 (SSTX+)
/M_SSTXM: C13.2, J1.8 (SSTX-)
/QSPI_SCLK: U1.6 (CLK), U13.52 (QSPI_SCLK)
/QSPI_SD0: U1.5 (DI(IO0)), U13.53 (QSPI_SD0)
/QSPI_SD1: U1.2 (DO(IO1)), U13.55 (QSPI_SD1)
/QSPI_SD2: U1.3 (/WP(IO2)), U13.54 (QSPI_SD2)
/QSPI_SD3: U1.7 (/HOLD_/RESET), U13.51 (QSPI_SD3)
/QSPI_SS: R11.1, R12.2, U1.1 (/CS), U13.56 (QSPI_SS_N)
/RPI_XIN: C52.1, U10.1, U13.20 (XIN)
/RPI_XOUT: R20.2, U13.21 (XOUT)
/S0_D: J2.3 (D+), U4.1 (USB_DP_DN1)
/S0_DM: J2.2 (D-), U4.2 (USB_DM_DN1)
/S0_SSRX: J2.6 (SSRX+), U4.6 (USB_SSRXP_DN1)
/S0_SSRXM: J2.5 (SSRX-), U4.7 (USB_SSRXM_DN1)
/S0_SSTX: C16.2, J2.9 (SSTX+)
/S0_SSTXM: C15.2, J2.8 (SSTX-)
/S1_D: J7.3 (D+), U4.9 (USB_DP_DN2)
/S1_DM: J7.2 (D-), U4.10 (USB_DM_DN2)
/S1_SSRX: J7.6 (SSRX+), U4.14 (USB_SSRXP_DN2)
/S1_SSRXM: J7.5 (SSRX-), U4.15 (USB_SSRXM_DN2)
/S1_SSTX: C18.2, J7.9 (SSTX+)
/S1_SSTXM: C17.2, J7.8 (SSTX-)
/S2_D: U4.17 (USB_DP_DN3), U5.18 (U2DP)
/S2_DM: U4.18 (USB_DM_DN3), U5.17 (U2DM)
/S2_SSRX: U4.22 (USB_SSRXP_DN3), U5.16 (U3SSRXP)
/S2_SSRXM: U4.23 (USB_SSRXM_DN3), U5.15 (U3SSRXN)
/S2_SSTX: C25.2, U5.13 (U3SSTXP)
/S2_SSTXM: C24.2, U5.12 (U3SSTXN)
/S3_D: R13.2, U4.24 (USB_DP_DN4)
/S3_DM: R14.2, U4.25 (USB_DM_DN4)
/pwrCtrl0: R27.1, U4.36 (PWRCTL1/BATEN1), U11.4 (EN1)
/pwrCtrl1: R28.1, U4.35 (PWRCTL2/BATEN2), U11.5 (EN2)
/pwrCtrl2: R35.2, U4.33 (PWRCTL3/BATEN3), U12.4 (EN1)
/pwrCtrl3: R36.2, U4.32 (PWRCTL4/BATEN4), U12.5 (EN2)
/pwrOver0: R30.1, U4.46 (OVERCUR1Z), U11.10 (~FAULT1)
/pwrOver1: R29.1, U4.47 (OVERCUR2Z), U11.6 (~FAULT2)
/pwrOver2: R33.1, U4.44 (OVERCUR3Z), U12.10 (~FAULT1)
/pwrOver3: R34.1, U4.43 (OVERCUR4Z), U12.6 (~FAULT2)
/pwrVbus0: C64.2, C65.2, FB3.2, U11.9 (OUT1)
/pwrVbus1: C66.2, C67.2, FB4.1, U11.8 (OUT2)
/pwrVbus2: C68.2, C70.2, FB5.1, U12.9 (OUT1)
/pwrVbus3: C69.2, C71.2, U12.8 (OUT2)
/ring_audio_r: J5.3, U8.16 (LINEVOUTR)
/sleeve_mic_l: C42.1, J5.1, R15.2
/sleeve_mic_r: C43.1, J6.1, R16.2
/tip_audio_l: J5.2, U8.1 (LINEVOUTL)
GND: C1.1, C2.1, C3.1, C5.2, C6.1, C7.1, C8.1, C10.2, C12.1, C19.1, C20.2, C21.2, C22.2, C23.2, C26.2, C27.2, C28.2, C29.2, C30.2, C31.2, C32.2, C33.2, C34.2, C38.2, C39.2, C40.1, C41.1, C44.1, C45.1, C46.1, C47.2, C49.1, C50.1, C51.1, C52.2, C53.2, C54.2, C55.2, C56.2, C57.2, C58.2, C59.1, C60.1, C61.1, C62.1, C63.1, C64.1, C65.1, C66.1, C67.1, C68.1, C69.1, C70.1, C71.1, C72.2, C73.2, C74.2, FB6.2, FB7.2, FB8.2, FB9.2, J1.4 (GND), J1.7 (GND_DRAIN), J2.4 (GND), J2.7 (GND_DRAIN), J3.10, J4.2, J5.4, J6.4, J7.4 (GND), J7.7 (GND_DRAIN), R2.2, R6.2, R8.1, R10.2, R22.2, R23.2, R24.2, R25.2, R26.2, R31.2, R32.2, U1.4 (GND), U2.3 (GND), U3.3 (GND), U4.65 (VSS), U5.25 (EEDI/SPIDI/ENSWREG), U5.29 (GND), U5.41 (GND__1), U7.7 (AGND), U7.12 (DGND), U7.20 (MD6), U7.21 (MD5), U7.22 (MD4), U7.23 (MD2), U7.24 (MD3), U7.25 (MD1), U7.26 (MD0), U8.4 (LINEGND), U8.13 (AGND), U9.1 (GND), U10.2, U10.4, U11.1 (GND), U11.11 (PAD), U12.1 (GND), U12.11 (PAD), U13.19 (TESTEN), U13.57 (GND)
unnamed: C53.1, R20.1, U10.3
unnamed: C72.1, C73.1, C74.1, U13.23 (DVDD), U13.50 (DVDD__1)
unnamed: FB7.1, J3.S1 (SHIELD), J3.S2 (SHIELD)
unnamed: FB6.1, J1.SH1 (SHIELD), J1.SH2 (SHIELD__1)
unnamed: FB8.1, J2.SH1 (SHIELD), J2.SH2 (SHIELD__1)
unnamed: C59.2, FB3.1, J2.1 (VBUS)
unnamed: C19.2, J3.1
unnamed: J3.11, J3.14, R9.1
unnamed: J4.1, R11.2
unnamed: FB9.1, J7.SH1 (SHIELD), J7.SH2 (SHIELD__1)
unnamed: C60.2, FB4.2, J7.1 (VBUS)
unnamed: C4.1, U2.4 (BST)
unnamed: R1.2, U2.5 (EN)
unnamed: R2.1, R3.1, U2.6 (FB)
unnamed: C4.2, L2.1, U2.2 (SW)
unnamed: C9.1, U3.4 (BST)
unnamed: R4.2, U3.5 (EN)
unnamed: C11.2, R5.1, R6.1, U3.6 (FB)
unnamed: C9.2, L3.1, U3.2 (SW)
unnamed: R24.1, U4.45 (AUTOENZ/HS_SUSPEND)
unnamed: R25.1, U4.40 (FULLPWRMGMTZ/SMBA1/SS_UP)
unnamed: R26.1, U4.42 (GANGED/SMBA2/HS_UP)
unnamed: C58.1, U4.50 (GRSTZ)
unnamed: R22.1, U4.49 (TEST)
unnamed: R23.1, U4.64 (USB_R1)
unnamed: C15.1, U4.4 (USB_SSTXM_DN1)
unnamed: C17.1, U4.12 (USB_SSTXM_DN2)
unnamed: C24.1, U4.20 (USB_SSTXM_DN3)
unnamed: C13.1, U4.56 (USB_SSTXM_UP)
unnamed: C16.1, U4.3 (USB_SSTXP_DN1)
unnamed: C18.1, U4.11 (USB_SSTXP_DN2)
unnamed: C25.1, U4.19 (USB_SSTXP_DN3)
unnamed: C14.1, U4.55 (USB_SSTXP_UP)
unnamed: R7.2, R8.2, U4.48 (USB_VBUS)
unnamed: FB2.2, U4.16 (VDD33), U4.34 (VDD33__1), U4.52 (VDD33__2), U4.63 (VDD33__3)
unnamed: FB1.2, U4.5 (VDD), U4.8 (VDD__1), U4.13 (VDD__2), U4.21 (VDD__3), U4.28 (VDD__4), U4.31 (VDD__5), U4.51 (VDD__6), U4.57 (VDD__7)
unnamed: C22.1, C23.1, U5.20 (AVDD33__1)
unnamed: R10.1, U5.38 (RSET)
unnamed: C20.1, C21.1, U5.19 (U2VDD10)
unnamed: C61.2, FB5.2, U5.21 (VDD5), U5.27 (VDDREG5)
unnamed: C38.1, U7.11 (LDO)
unnamed: R15.1, R16.1, U7.5 (MICBIAS)
unnamed: C42.2, U7.3 (VINL1_VIN1P)
unnamed: C43.2, U7.4 (VINR1_VIN2P)
unnamed: C39.1, U7.6 (VREF)
unnamed: C45.2, U7.10 (XI)
unnamed: C44.2, U7.9 (XO)
unnamed: C48.1, U8.5 (CPCA)
unnamed: C48.2, U8.3 (CPCB)
unnamed: C46.2, U8.2 (CPVOUTN)
unnamed: C50.2, U8.14 (VMID)
unnamed: R31.1, U11.7 (ILIM)
unnamed: R32.1, U12.7 (ILIM)
unnamed: R14.1, U13.46 (USB_DM)
unnamed: R13.1, U13.47 (USB_DP)
VBUS: C1.2, C2.2, C3.2, C6.2, C7.2, C8.2, C12.2, C62.2, C63.2, J1.1 (VBUS), R1.1, R4.1, R7.1, U2.1 (VIN), U3.1 (VIN), U11.2 (IN), U11.3 (IN__1), U12.2 (IN), U12.3 (IN__1)

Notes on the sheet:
FOR RPI (12 MHz)
RPI_AUDIO
CLK_GEN
make sure R is close to RPI
AUDIO OUT
RPI_TEMP_SENSOR
RPI_CTRL
RPI-FLASH
USB HUB
make sure C is close to pin 45
make sure C is close to pin 44
FOR ETH (25 MHz)
AUDIO IN
ETHERNET
FOR HUB (24MHz)
THERMO SENSOR
POWER

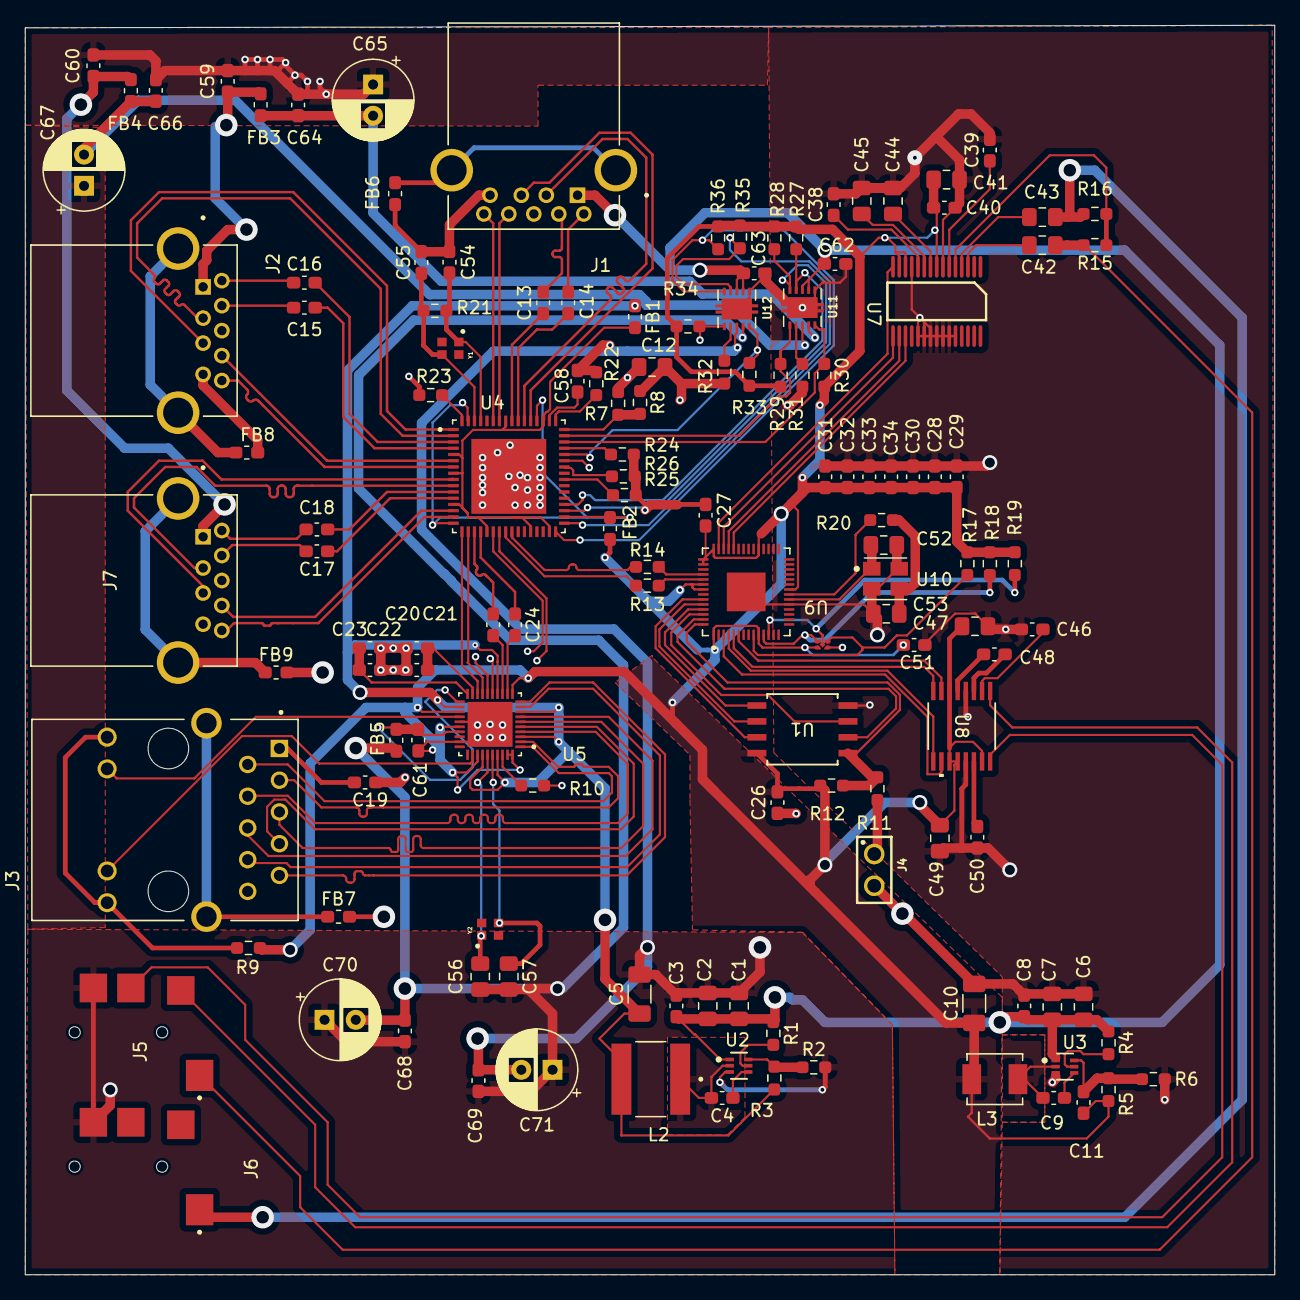
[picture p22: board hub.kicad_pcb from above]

Board: 4 copper layers, 100.0 x 100.0 mm, 136 parts (0 on the bottom side), 133 nets.
